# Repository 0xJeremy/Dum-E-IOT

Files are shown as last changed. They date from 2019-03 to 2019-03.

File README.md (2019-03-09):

# Dum-E IOT

This repository holds all files needed to create a swarm of internet enabled robotic arms. All .dxf files and 3D models can be found in the "Robot Files" folder. All code needed to host a Node.js Heroku server is also included here. 

This project was made for MakeHarvard 2019 and is intended as a teaching tool for robot enthusiasts. The board used to control these arms is a generic NodeMCU ESP-8266 Wifi board. The servos used were standard 180° rotation servos. The CAD files can be modified to fit servos of different sizes. 

A wiring diagram is not currently available but will be created in the near future.

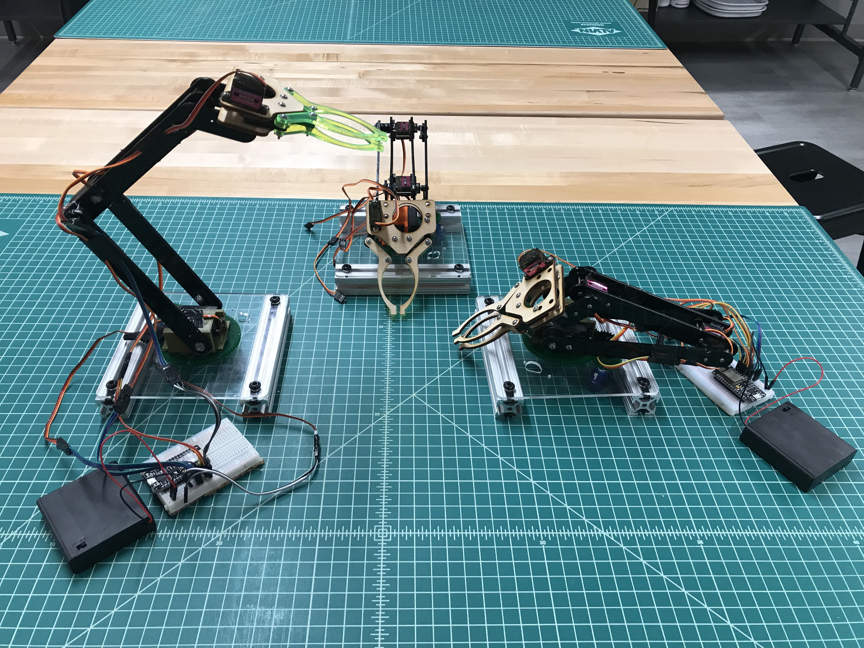
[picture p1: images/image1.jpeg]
Dum-E IOT Arms


### NOTE: NodeMCU will not flash if 6V battery pack is plugged in and off. Turn on 6V power to flash board.

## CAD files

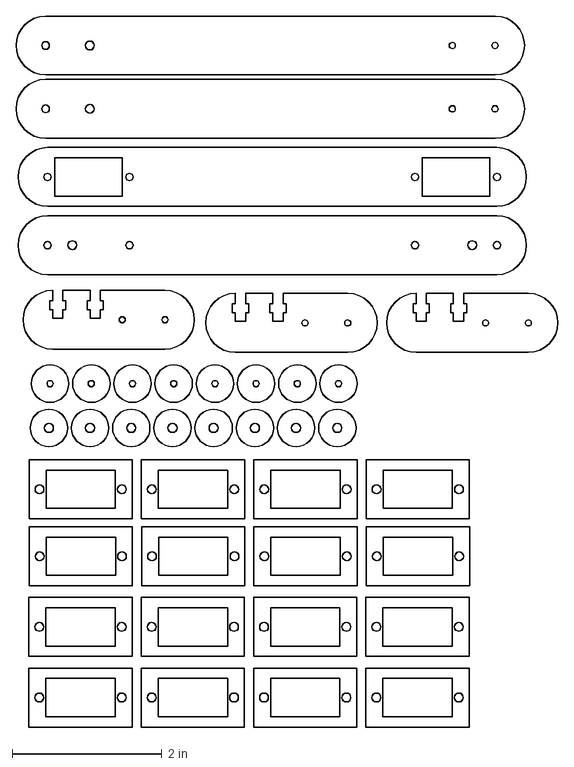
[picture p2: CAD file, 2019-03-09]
Robot Files/Arm Files/arm assembly 2.dxf
7.23 x 9.49 in

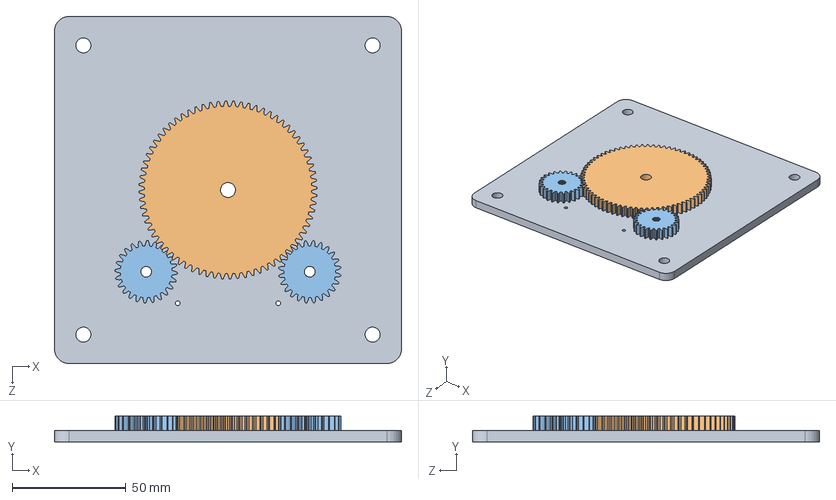
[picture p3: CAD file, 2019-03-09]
Robot Files/Base Files/base-and-gears-assem.SLDASM
152.4 x 11.4 x 152.4 mm
bottom-plate-sketch
3in-72tooth-gear-with-quarter-inch-hole
1in-24tooth-gear-with-20tooth-servo-spline-cutout x 2

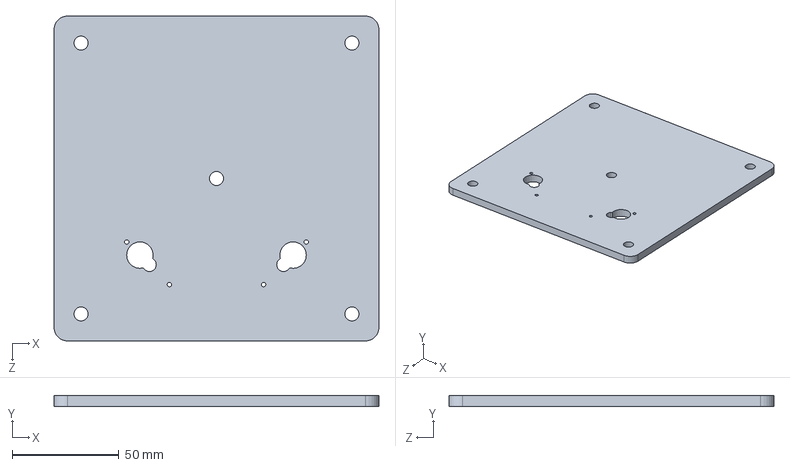
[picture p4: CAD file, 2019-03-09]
Robot Files/Base Files/bottom-plate-double-servo-sketch.SLDPRT
152.4 x 5.00 x 152.4 mm

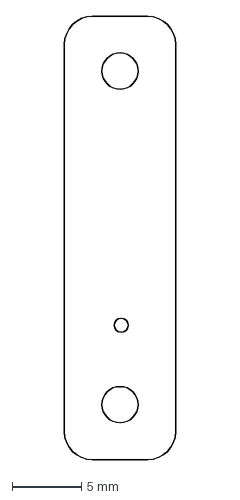
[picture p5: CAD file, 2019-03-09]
Robot Files/Gripper Files/BoneSmallerHole3.dxf
8.00 x 31.9 mm

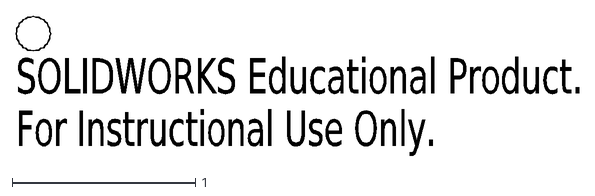
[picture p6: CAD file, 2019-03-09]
Robot Files/Base Files/20tooth-servo-spline-cutout.DXF
SOLIDWORKS Educational Product.
For Instructional Use Only.

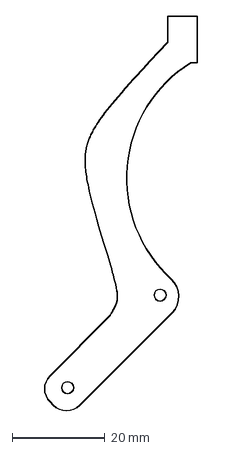
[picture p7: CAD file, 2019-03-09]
Robot Files/Gripper Files/GripperArm 1.dxf
33.4 x 85.2 mm

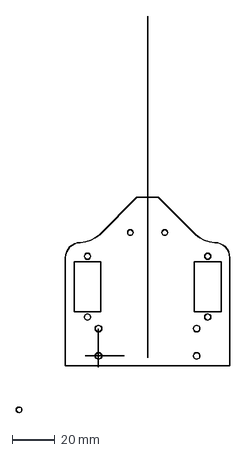
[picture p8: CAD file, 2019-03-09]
Robot Files/Base Files/Baseplate1.dxf
99.4 x 184.6 mm

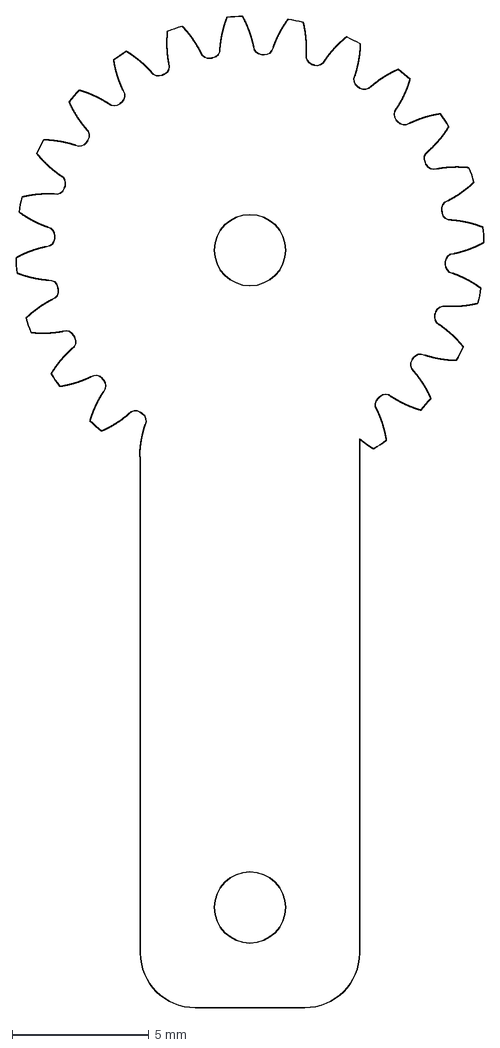
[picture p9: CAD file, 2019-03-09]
Robot Files/Gripper Files/GearBone 1.dxf
17.1 x 36.2 mm

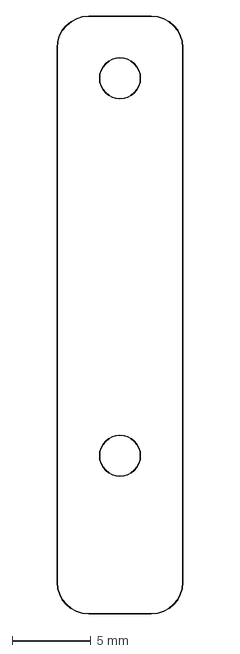
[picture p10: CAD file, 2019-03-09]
Robot Files/Gripper Files/LongBone 1.dxf
8.00 x 38.0 mm

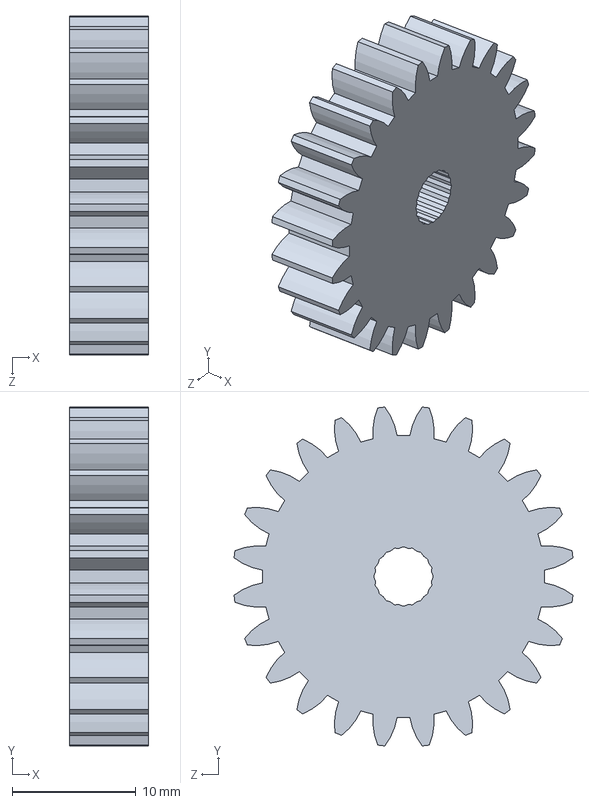
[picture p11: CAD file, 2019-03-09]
Robot Files/Base Files/1in-24tooth-gear-with-20tooth-servo-spline-cutout.SLDPRT
6.35 x 27.4 x 27.4 mm

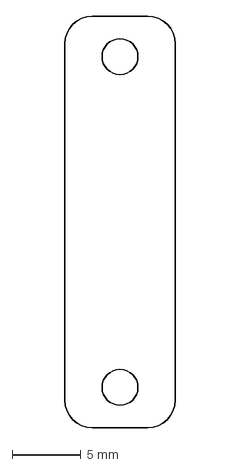
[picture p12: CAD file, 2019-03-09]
Robot Files/Gripper Files/Bone 1.dxf
8.00 x 29.9 mm

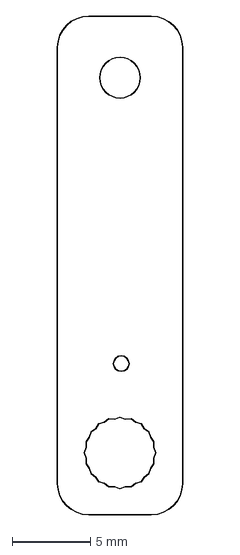
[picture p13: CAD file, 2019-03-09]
Robot Files/Gripper Files/BoneBiggerHole3.dxf
8.00 x 31.9 mm

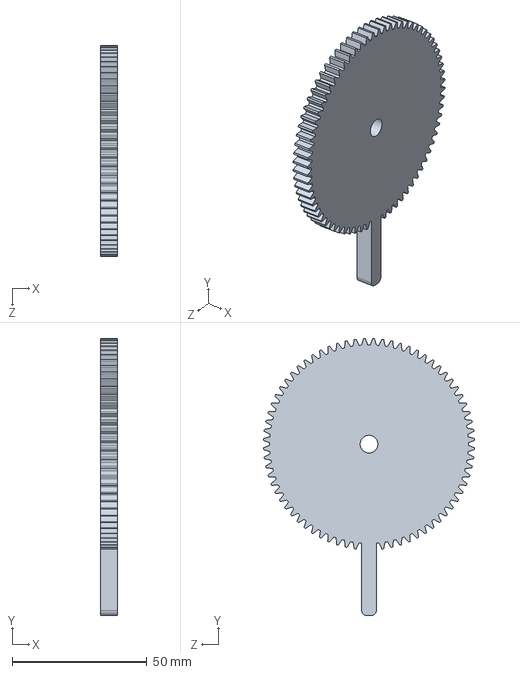
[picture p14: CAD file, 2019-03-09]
Robot Files/Base Files/3in-72tooth-gear-with-quarter-inch-hole-mechanical-stop.SLDPRT
6.35 x 102.6 x 78.3 mm

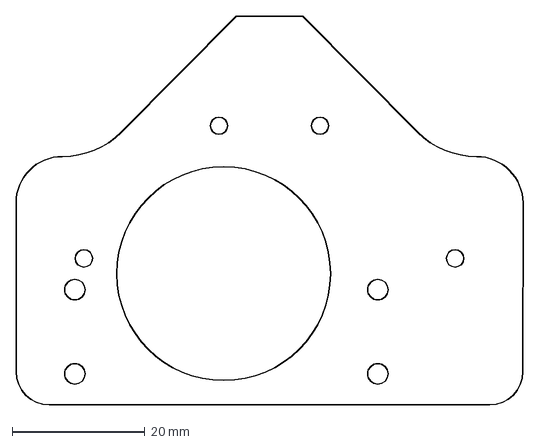
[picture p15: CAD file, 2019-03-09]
Robot Files/Base Files/BaseplateBottom3.dxf
76.5 x 58.6 mm

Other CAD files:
Robot Files/Base Files/bottom-plate-single-servo-sketch.SLDPRT
Robot Files/Base Files/BaseplateTop3.dxf
Robot Files/Base Files/3in-72tooth-gear-with-quarter-inch-hole.SLDPRT
Robot Files/Base Files/20tooth-servo-spline-sketch.SLDPRT
Robot Files/Arm Files/BigWasher.dxf
Robot Files/Arm Files/LilWasher.dxf
Robot Files/Base Files/1in-24tooth-gear-with-20tooth-servo-spline-cutout.DXF
Robot Files/Base Files/3in-72tooth-gear-with-quarter-inch-hole-mechanical-stop.DXF
Robot Files/Base Files/3in-72tooth-gear-with-quarter-inch-hole.DXF
Robot Files/Base Files/bottom-plate-double-servo-sketch.DXF
Robot Files/Base Files/bottom-plate-single-servo-sketch.DXF

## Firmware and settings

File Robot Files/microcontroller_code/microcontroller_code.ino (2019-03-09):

#include <Servo.h>
#include <ESP8266WiFi.h>
#include <ESP8266HTTPClient.h>

// Define pins for servos
#define gripperPin 5
#define wristPin 4
#define elbowPin 0
#define shoulderPin 2
#define basePin 14

// Define parameters for each servo
#define minPulse180 400
#define maxPulse180 2400
#define minPulseShoulder 800
#define maxPulseShoulder 2200
#define minPulseCont 700
#define maxPulseCont 2300
#define timeWaitAngle 25
#define timeWaitSpeed 100

// Define constants for wifi
const char* ssid = "iPhone";
const char* password = "Artemis9698";

// Define servo objects
Servo gripper;
Servo wrist;
Servo elbow;
Servo shoulder;
Servo base;

// setServoAngle - Sets angle of servo
void setServoAngle(Servo &thisServo, int minPulse, int maxPulse, int angle, int minAngle, int maxAngle){
  int pulse = map(angle, minAngle, maxAngle, minPulse, maxPulse);
  thisServo.writeMicroseconds(pulse);
  delay(timeWaitAngle);
}

// turnContServo - turns continuous servo 
void turnContServo(Servo &thisServo, bool cw, int minPulse, int maxPulse){
  if(cw){
    thisServo.writeMicroseconds(minPulse);
    delay(timeWaitSpeed);
  }else{
    thisServo.writeMicroseconds(maxPulse);
    delay(timeWaitSpeed);
  }
  thisServo.writeMicroseconds((maxPulse + minPulse)/2);
}

// get_action - get action command from website
String get_action() {
  String payload = "error";
    if (WiFi.status() == WL_CONNECTED) {
      HTTPClient http;
      http.begin("http://makeharvard-mk1.herokuapp.com/get_jarvis");  //Change per robot
      int httpCode = http.GET();
      if (httpCode > 0) {
        payload = http.getString();
        Serial.println(payload);
    }
    http.end();
  }
  return payload;
}

void setup() {
  // Attach servos to pins
  gripper.attach(gripperPin, minPulse180, maxPulse180);
  wrist.attach(wristPin, minPulse180, maxPulse180);
  elbow.attach(elbowPin, minPulse180, maxPulse180);
  shoulder.attach(shoulderPin, minPulseShoulder, maxPulseShoulder);
  base.attach(basePin, minPulseCont, maxPulseCont);
  
  Serial.begin(9600);

  // Connect to wifi
  WiFi.begin(ssid, password);
  while (WiFi.status() != WL_CONNECTED) {
    delay(1000);
    Serial.println("Connecting...");
  }
  Serial.println("Connected");
}

void loop() {
  
  String action = get_action();

  switch (action[0]){

    case 'g':
      // Move gripper
      if(action[1] == 'o'){
        setServoAngle(gripper, minPulse180, maxPulse180, 180, 0, 180);
      }else{
        setServoAngle(gripper, minPulse180, maxPulse180, 0, 0, 180);
      }
      break;

    case 'w':
      // Move wrist
      if(action[1] == '0'){
        setServoAngle(wrist, minPulse180, maxPulse180, 0, 0, 180);
      }
      else if(action[1] == '4'){
        setServoAngle(wrist, minPulse180, maxPulse180, 45, 0, 180);
      }
      else if(action[1] == '9'){
        setServoAngle(wrist, minPulse180, maxPulse180, 90, 0, 180);
      }
      else if(action[2] == '3'){
        setServoAngle(wrist, minPulse180, maxPulse180, 135, 0, 180);
      }
      else if(action[2] == '8'){
        setServoAngle(wrist, minPulse180, maxPulse180, 180, 0, 180);
      }
      break;

    case 'e':
      // Move elbow
      if(action[1] == '0'){
        setServoAngle(elbow, minPulse180, maxPulse180, 0, 0, 180);
      }
      else if(action[1] == '4'){
        setServoAngle(elbow, minPulse180, maxPulse180, 45, 0, 180);
      }
      else if(action[1] == '9'){
        setServoAngle(elbow, minPulse180, maxPulse180, 90, 0, 180);
      }
      else if(action[2] == '3'){
        setServoAngle(elbow, minPulse180, maxPulse180, 135, 0, 180);
      }
      else if(action[2] == '8'){
        setServoAngle(elbow, minPulse180, maxPulse180, 180, 0, 180);
      }
      break;

    case 's':
      // Move shoulder
      if(action[1] == '0'){
        setServoAngle(shoulder, minPulse180, maxPulse180, 0, 0, 180);
      }
      else if(action[1] == '4'){
        setServoAngle(shoulder, minPulse180, maxPulse180, 45, 0, 180);
      }
      else if(action[1] == '9'){
        setServoAngle(shoulder, minPulse180, maxPulse180, 90, 0, 180);
      }
      break;

    case 'b':
      // Turn base
      if(action[1] == 'f'){
        turnContServo(base, true, minPulseCont, maxPulseCont);
      }
      else if(action[1] == 'r'){
        turnContServo(base, false, minPulseCont, maxPulseCont);
      }
      break;

    case 'E':
      //command
      Serial.println("ERROR: Something went wrong!");
      break;
    
    default:
      Serial.println("No command received.");
      break;
    
  }

}

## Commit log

2019-02-07 Added Gripper Files
    [Bone 1.dxf, BoneBiggerHole3.dxf, BoneSmallerHole3.dxf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]
2019-02-07 Added Arm Files
    [1in-24tooth-gear-with-20tooth-servo-spline-cutout.DXF, 3in-72tooth-gear-with-quarter-inch-hole.DXF, Baseplate1.dxf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]
2019-02-07 Added CAD Models
    [1in-24tooth-gear-with-20tooth-servo-spline-cutout.SLDPRT, 20tooth-servo-spline-cutout.DXF, 20tooth-servo-spline-sketch.SLDPRT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]
2019-02-08 Updated microcontroller_code
    Base servo now stops after timeWaitSpeed microseconds
2019-02-10 Update README.md
    The battery pack causes a huge issue. If it is plugged in, make sure it is TURNED ON!
2019-03-09 Large gear with mechanical stop. Base with single servo.
    Updated several files names to be more explicit. Also added new files so the large base gear has a mechanical stop and the base plate has a cutout for only one servo.
    [3in-72tooth-gear-with-quarter-inch-hole-mechanical-stop.DXF, 3in-72tooth-gear-with-quarter-inch-hole-mechanical-stop.SLDPRT, bottom-plate-double-servo-sketch.D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]
2019-03-09 Fixed Buttons
2019-03-09 Removed unneeded files and reorganized repo
    Removed unrelated files that were accidentally uploaded to the repo. Also reorganizing repo to make sure files are in the correct directory.
    [base-and-gears-assem.SLDASM, bottom-plate-sketch.SLDPRT, fullMotorHousing.STL]
